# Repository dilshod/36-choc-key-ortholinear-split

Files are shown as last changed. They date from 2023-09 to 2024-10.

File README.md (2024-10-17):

# 1984 - 36 ortholinear split keyboard

## Keyboard Specifications:

* Type: Ortholinear Split Keyboard
* Key Layout: 3x5 keys + 3 thumb keys
* Switch Type: Choc v1 switches (Kailh 1350) or kailh x switches
* Wireless: Yes
* Controller: Seeeduino XIAO Ble

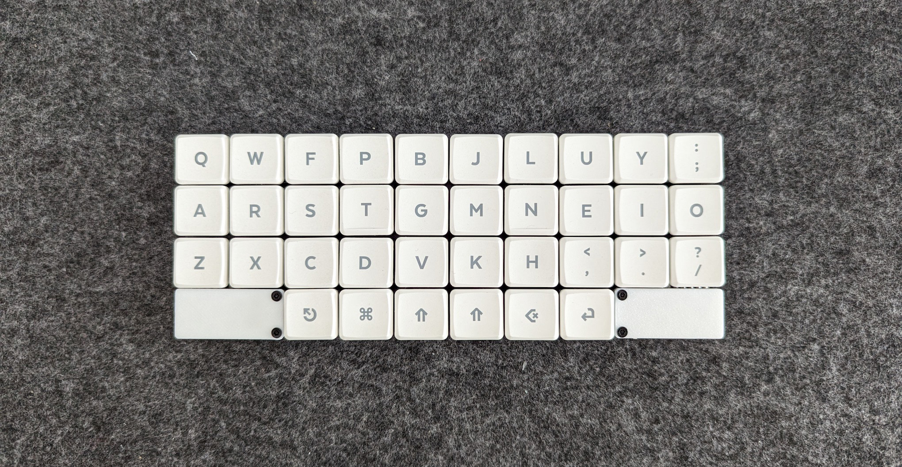
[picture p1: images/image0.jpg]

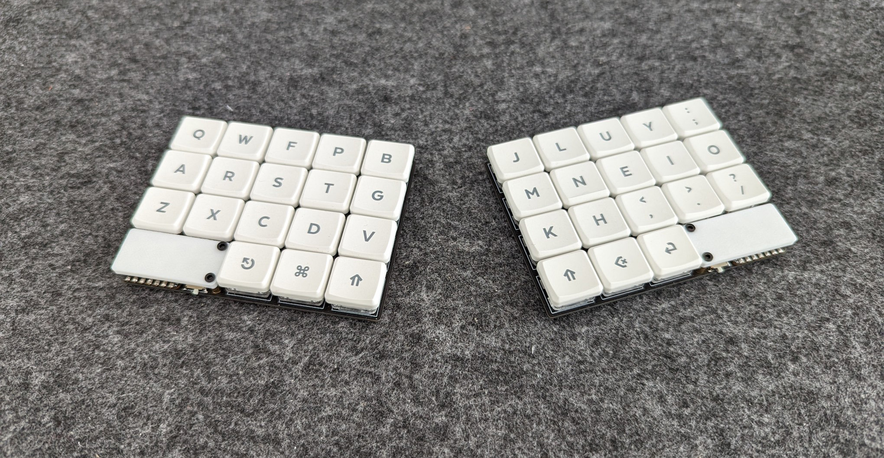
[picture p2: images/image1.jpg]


## Parts List

| Name | Count | Remarks | Where to buy |
| --- | --- | --- | --- |
| Choc v1 switches | 36 | Kailh 1350 | https://aliexpress.com/item/1005003211600725.html |
| Diode | 36 | SOD123 | https://aliexpress.com/item/32354597825.html |
| Toggle Slide Switch | 2 | SMD | https://aliexpress.com/item/32856542440.html |
| Spacer | 4 | Female Female M2x5 | https://aliexpress.com/item/4001271908929.html?sku_id=10000015551405882 |
| Seeeduino XIAO Ble | 2 | | https://aliexpress.com/item/1005004459618789.html |
| Screw | 8 | M2x5 | https://aliexpress.com/item/1005003116717551.html?sku_id=12000024187943658 |
| Choc Keycaps | | | https://keebd.com/products/mbk-legend-40s-set |
| Rubber Feet | 4 | | https://aliexpress.com/item/1005005249895853.html |
| 3.7v LiPo battery | 2 | | Various models (601010, 501010, 401010, 400909) - 3.7v, 25mA-55mA |

## Building Instructions

1. Solder the controller, diods and toggle switch on the top.
2. Then solder the switches over the diodes and attach the batteries.

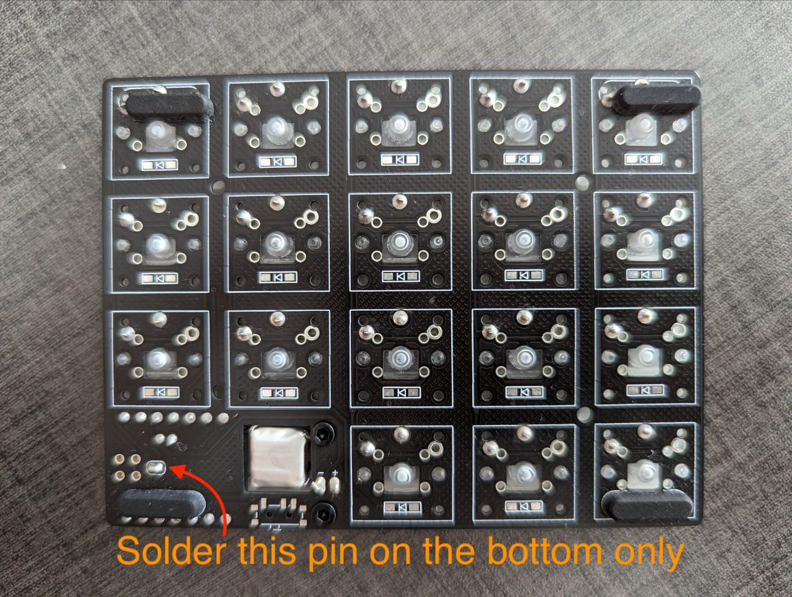
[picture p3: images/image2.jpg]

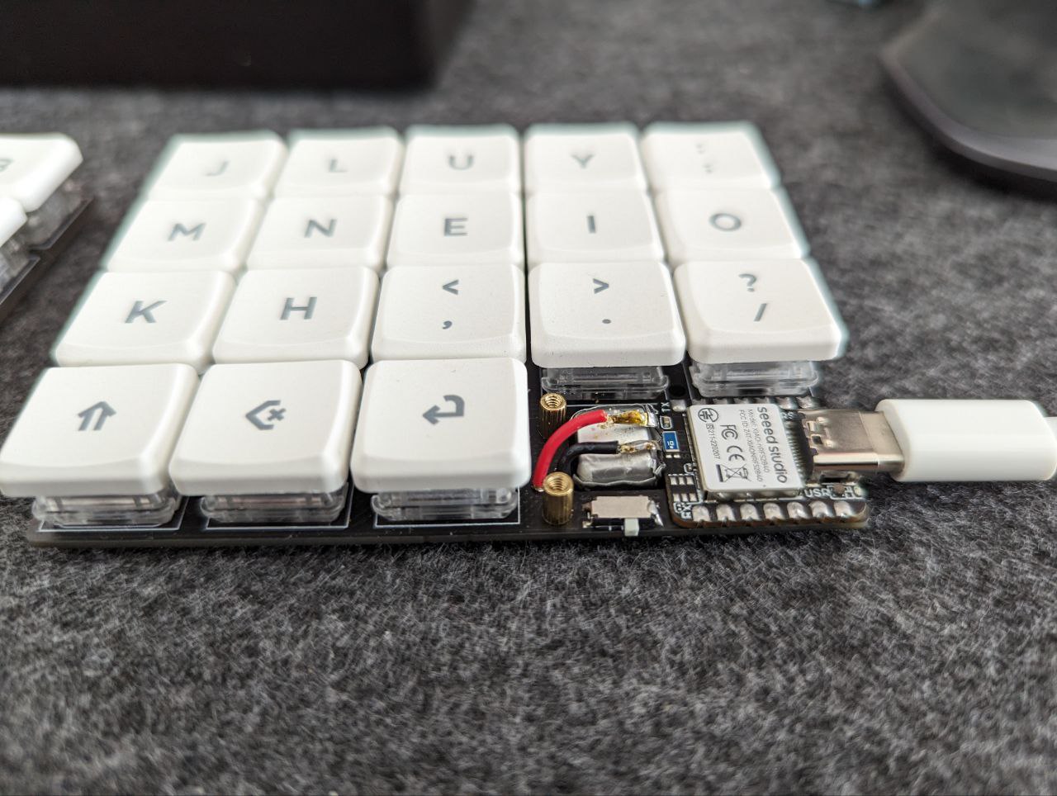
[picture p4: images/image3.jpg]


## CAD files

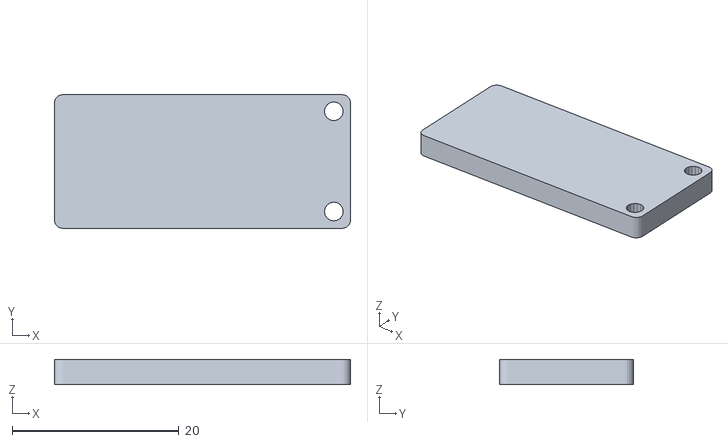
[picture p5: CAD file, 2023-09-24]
cover/cover.stl
35.5 x 16.0 x 3.00

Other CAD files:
cover/cover.blend

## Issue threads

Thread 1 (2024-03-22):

Pimoroni Trackball Support?

t0bybr, 2024-03-22:
Hi,
I really love this Design and I'm waiting at the moment for the mcus to arrive to build. Thank you by the way to make it open source.
I was wondering if it would be possible to add a Pimoroni Trackball to this keyboard? It connects via I2C and is supported by ZMK so I think it should work but I'm not sure. Do you know if it would work?
Thanks in advance
Toby

dilshod, 2024-03-22:
Hi,
I think it should work.
I never tried it because I read it has high power consumption, according to N76E003 datasheet it consumes at least 4 times more power than xiao ble both in idle mode.

t0bybr, 2024-03-28:
Thanks for your response. I'm designing a case at the moment and there would be space for a bigger battery.

What do you think would be the best way to connect the Trackball?

dilshod, 2024-03-29:
sda and scl pins are already used by keys, but you can use p0.02 and p0.03 pins, you will have to solder directly to the module pins: trackpoints sda to p0.02, scl to p0.03, gnd and 3v3 pins. As I understand int pin can be left unconnected.

Patch zmk from here:
https://www.reddit.com/r/ErgoMechKeyboards/comments/pxbaw0/pimoroni_pim447_trackball_support_in_zmk_firmware/

And change i2c in your overlay file to use p0.02 and p0.03 pins.
It's a theory, I'm not sure if it will work. If you try it, I'd love to hear how it goes.

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

t0bybr, 2024-04-01:
Thank you for the detailed explanation. Is there another free pin? Then I could connect INT in case it gets used sometime. And if I get it to work, I'll of course let you know.

dilshod, 2024-04-02:
There are two NFC pins on the bottom of the module, you can use them.
In order to use them add this line to your zmk config:
```
CONFIG_NFCT_PINS_AS_GPIOS=y
```
NFC pins are: p0.09 and p0.10

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

suriaribeiro, 2024-04-10:
Did you manage to get it to work? It would be greT if you could share your zmk config as I am trying to do the same thing

t0bybr, 2024-04-13:
Sorry, didn't have the time to try it yet. Hope to get to it this weekend. I will post results.

suriaribeiro, 2024-04-13:
Cool! Looking forward to how you get on.  The pimoroni trackball would be a great companion to xiao ble based keyboards.

suriaribeiro, 2024-04-13:
I gave an initial try but failed miserably https://github.com/suriaribeiro/zmk-config-acari/tree/pimoroni-branch

t0bybr, 2024-08-15:
Sorry for the late reply but I didn't have time to build the keyboard until now. But now I built it and the keyboard itself is working fine, which is great because I'm not the best in regards to soldering.

But I also can't get the trackball working. If I use the zmk fork from https://github.com/cdc-mkb/zmk/commits/mouse-pim447 it fails building because it has no board definition of the xiao BLE. If I use regular zmk and try to merge the PIM447 files into it, I can get it to build but the trackball isn't working. My problem is that I never worked with zmk before and I'm too unfamiliar with it at the moment.

t0bybr, 2024-10-02:
6 weeks later and I made progress. I tried to convert the official Pimoroni PIM447 C++ driver and it works. Here is the driver as a module: https://github.com/t0bybr/pim447 and here my current config: https://github.com/t0bybr/zmk-config-kailhx. I'm still working at it so it might chance but for now I have the interrupt working, the movement in mouse and scroll mode (compatible with the ZMK pull request #2027), setting the leds works and it reacts to idle/deep sleep of the keyboard. But I don't know yet how long the battery lasts because I still have to finish the case.

t0bybr, 2024-10-20:
I used D0 (p0.02) for SDA and D1 (p0.03) for SCL and besides that the NFC Pin (p0.09) for the interrupt.

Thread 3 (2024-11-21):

through-hole vs SMD pads for mounting seeed xiao?

abliss, 2024-11-21:
Thanks for sharing this design. I have successfully assembled my first unit and am typing on it now!
I used PCBWay.com for the order, and while their customer service was excellent, they had some trouble mounting the seeed xiao directly to the through-holes. This resulted in me having to do some rework to get the units operational. I asked them about it and they strongly suggested switching the 16 connection points for the seeed xiao to SMD pads instead of through-holes.
I am wondering what you think about this. Do you have process suggestions for reliably soldering the seeed xiao directly to through-holes? Or do you think it would be easy/practical/a good idea to replace the through-holes with SMD pads in the pcb design? Or would it be better to use two rows of header-pins (plus two patch wires for the Bat+/- connection)?
Thanks again!

dilshod, 2024-11-22:
I had never soldered the controller that way, so I left the through-holes just in case, I think they can be changed to SMD pads.
